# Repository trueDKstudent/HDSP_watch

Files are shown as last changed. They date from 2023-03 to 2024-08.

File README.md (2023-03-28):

## Wrist watch on HDSP-2000 indicators

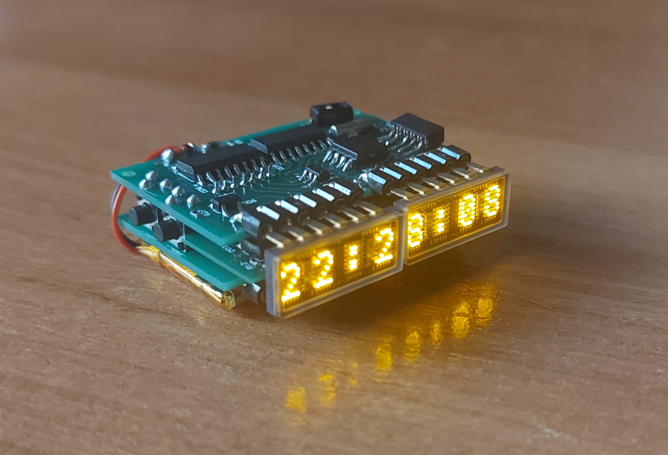
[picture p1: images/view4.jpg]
watch


### Introduction

Hello everyone, in this article I’d like to share with you my experience
in designing a digital wrist watch on rare and vintage LED indicators.
The main source of inspiration for this project came, of course, from
very unusual matrix LED indicators HDSP-2000 (fig. 1).

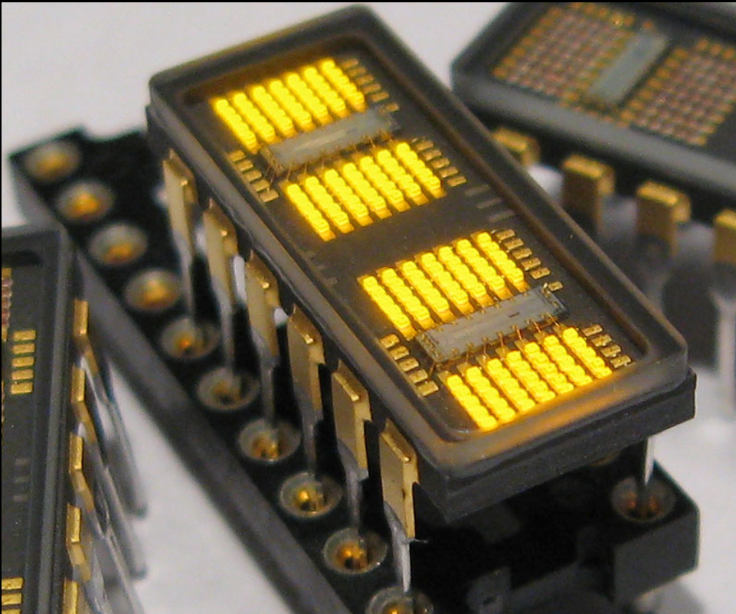
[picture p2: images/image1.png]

**Figure 1.**

When I saw them for the very first time I immediately fell in love with
them. First of all, it was very unlikely for me to ever find a 4 digit
matrix display in a 12-pin DIP ceramic package. Another stunning detail
about this display is that crystals on which located shift registers,
which are used to drive LED matrices, can be clearly seen through the
glass screen, as well as the golden wires that connect all the parts
together (fig. 2).

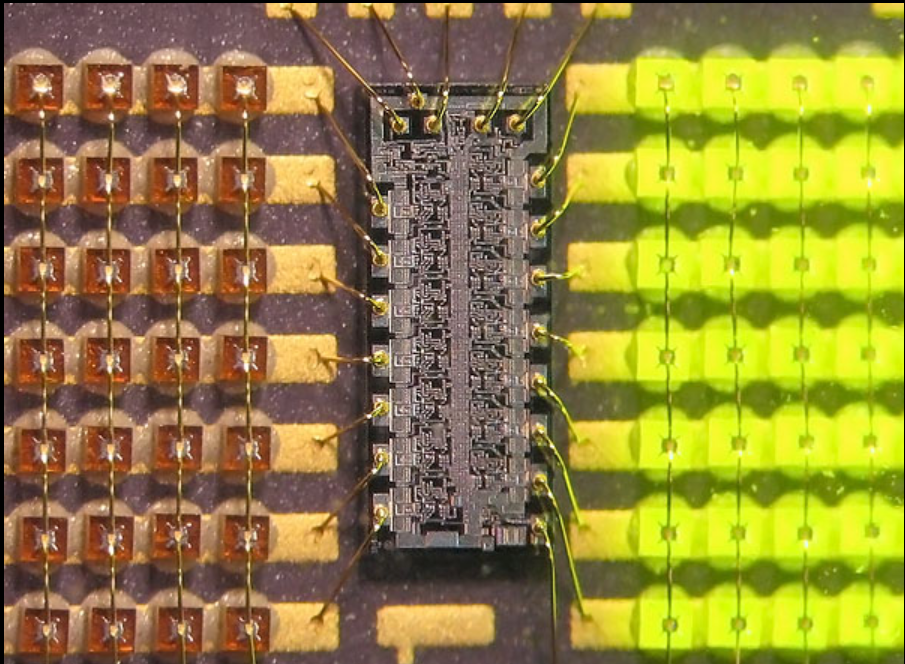
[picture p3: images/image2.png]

**Figure 2.**

I’ve bought several models of this displays, each of them has its own
color of light that is emitted from the LEDs.

- HDSP-2000 – has red LEDs and red filtering glass;
- HDPS-2001 – has yellow LEDs and clear glass;
- QDSP-2009 (HDSP-2002) – has green LEDs and clear glass as well;

As I got them I thought that it would be great idea to make on these
displays some sort of string line. The best devise into which I could
implement such a string, in my opinion, was a wrist watch. I think it
pretty cool to have a wrist watch with such an unusual and rare
indicators. Another reason why I decided to make this project is a lack
of any interesting tasks and projects, so I believed that designing of
this watches might be beneficial to my further grows as an electronic
engineer.

### Watches features

The first thing I decided to do was an inclusion of features, that will
have my wrist watch.

- The most obvious one is the display of time – hours, minutes and
seconds by clicking on specific button. A display of date, day of the
week, month, year and charge will be added as well.
- Another feature is indication of charging process, for example when
battery is charging some led should emit light and when the battery is
full – this led should turn off.
- The last feature is setting of time and date.

Of course, this is not the biggest list of possible features (alarm,
timers) but this watches do not need a myriad of them to be magnificent.
Just the look of its vintage indicators will make everyone adore it :)

Below are shown photos of finished wrist watch (without and with case).

With this link you can find video of this watch in action:
[link to video](https://drive.google.com/file/d/1nZPp8CitIWt24qjRfGPNrksItnVO5e3u/view?usp=share_link)

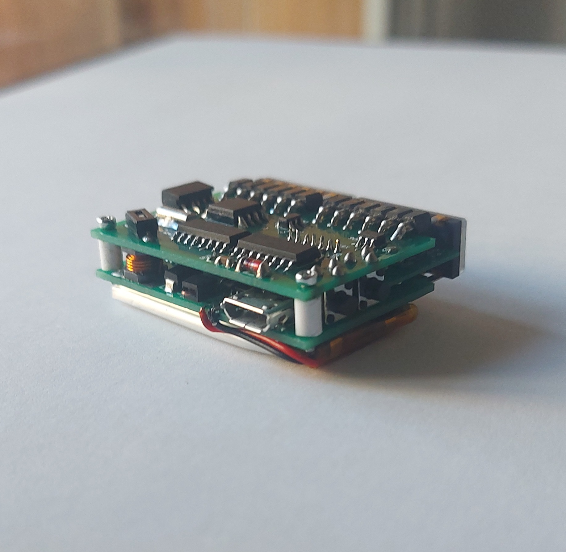
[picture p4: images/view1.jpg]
view 1


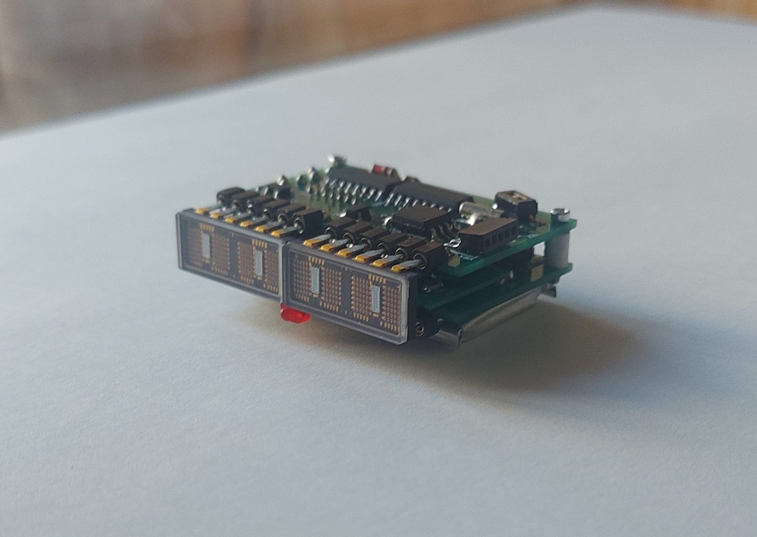
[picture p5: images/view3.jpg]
view 3


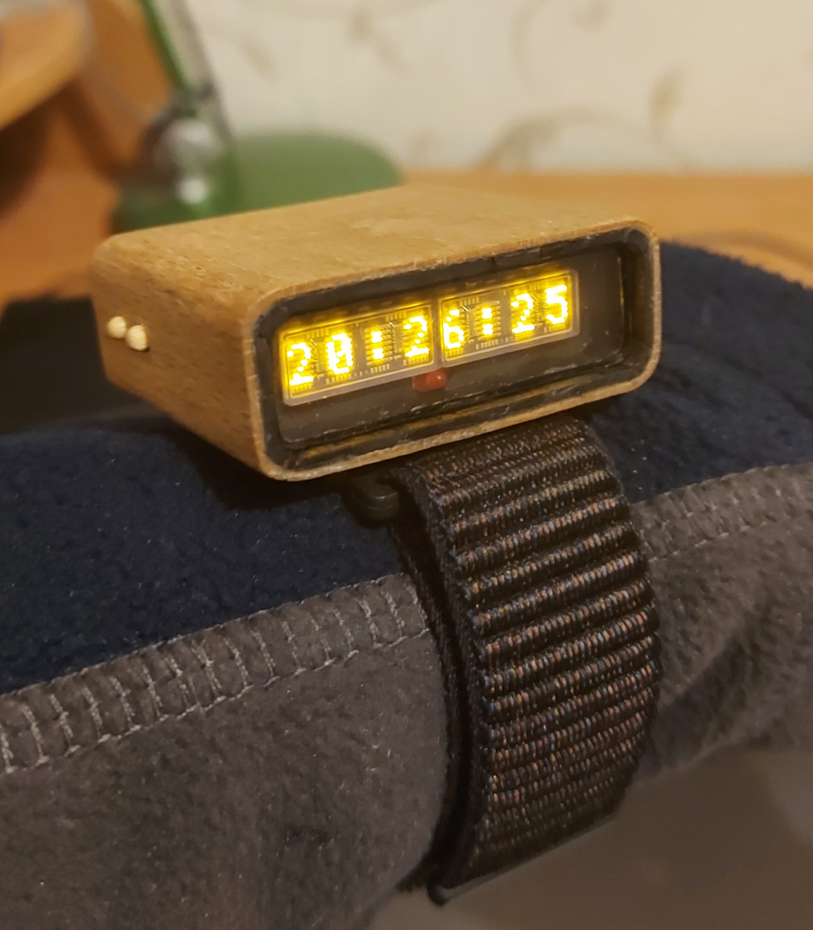
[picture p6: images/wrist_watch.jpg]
wrist watch


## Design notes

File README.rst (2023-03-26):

**Introduction**

Hello everyone, in this article I’d like to share with you my experience
in designing a digital wrist watch on rare and vintage LED indicators.
The main source of inspiration for this project came, of course, from
very unusual matrix LED indicators HDSP-2000 (fig. 1).


   Fig. 1

When I saw them for the very first time I immediately fell in love with
them. First of all, it was very unlikely for me to ever find a 4 digit
matrix display in a 12-pin DIP ceramic package. Another stunning detail
about this display is that crystals on which located shift registers,
which are used to drive LED matrices, can be clearly seen through the
glass screen, as well as the golden wires that connect all the parts
together (fig. 2).


   Fig. 2

I’ve bought several models of this displays, each of them has its own
color of light that is emitted from the LEDs.

- HDSP-2000 – has red LEDs and red filtering glass;

- HDPS-2001 – has yellow LEDs and clear glass;

- QDSP-2009 (HDSP-2002) – has green LEDs and clear glass as well;

As I got them I thought that it would be great idea to make on these
displays some sort of string line. The best devise into which I could
implement such a string, in my opinion, was a wrist watch. I think it
pretty cool to have a wrist watch with such an unusual and rare
indicators. Another reason why I decided to make this project is a lack
of any interesting tasks and projects, so I believed that designing of
this watches might be beneficial to my further grows as an electronic
engineer.

**Watches features**

The first thing I decided to do was an inclusion of features, that will
have my wrist watch.

- The most obvious one is the display of time – hours, minutes and
seconds by clicking on specific button. A display of date, day of the
week, month, year and charge will be added as well.

- Another feature is indication of charging process, for example when
battery is charging some led should emit light and when the battery is
full – this led should turn off.

- The last feature is setting of time and date.

Of course, this is not the biggest list of possible features (alarm,
timers) but this watches do not need a myriad of them to be magnificent.
Just the look of its vintage indicators will make everyone adore it :)

**Choosing the microcontoller**

When I was planing the entire project I also decided to make it more
challenging and interesting to me. And because of that chose a bit
unusual MCU for this watches. My pick stick to ATtiny85 - I beleived
that it would be an interesting challenge to make watch on this MC, but
later I had to switch to ATtiny85 and I will describe why so. Most basic
MC for such project would be ATmega328, which is used in Arduino UNO,
but again, it was not interesting enough to me and the solution on this
MC is already exist on the net.

Another reason why I’ve chosen AVR MCU but not ARM (STM32) or other is
because I’ve already had enough knowledge and skills about programming
such MCUs.

So, as you probably know, ATtiny85 has not a lot of pins, actually there
are only 5 pins which I could use to run an entire watch! It means that
I had to design various drivers and multiplexers to drive all the
devices with which ATtiny communicates.

**Display driver**

The key devices which are driven by MCU are of course indicators
HDSP-2000, without them entire project has no any sense. Due to the lack
of available pins in MCU, display driver should receive data from a
small amount of pins. If we look closer at the indicator, we’ll see that
it is basically a shift register which receives data through SPI bus. It
can be inferred, that the most vital signals for indicator are serial
clock and serial data signals. All other signals can be generated from
clock and data signals and I will explain how.

First of all, let’s have a look at columns signals. Each time a high
voltage level is applied to one of these pins the corresponding columns
in LED matrix are driven and the LEDs in this column emit light. It
means that after the new values have been stored to the shift registers
the next column should be driven. Basically, it is very similar to the
“running leds” projects, which can be easily built on decimal counters
like CD4017. Each time a new data is stored to the shift registers of
indicators, the counter CD4017 will count to the next value and the
corresponding output pin will drive the column of indicator.

Another problem is to get know when the transition of data to shift
registers is finished. This issue also can be solved with counters. By
counting the number of bits, which were transferred, it can be checked
whether or not the process is finished. In HDSP-2000 there are four
shift registers and each of them stores 7 bits, so the total data
capacity of indicator is 28 bits. Since two indicators are used in this
project, the capacity of display block is twice bigger, which is 56
bits. The amount of bits which were sent to the display can be obtained
from serial clock signal – each positive front of clock represents a one
bit of data that has been stored to the indicator. To count bits a
binary 7-stage counter CD4024 was used. The binary representation of
decimal number 56 is 111000, so the corresponding pins Q3, Q4, and Q5
are high when counter reach value 56. Early mentioned pins are tied to
single AND gate with 3 inputs. Output signal of AND gate is used as
clock signal for decimal counter CD4017. Since indicator HDSP-2000 has
only 5 columns counter CD4017 counts only from value 1 to 5. When
counter reaches value 5, corresponding pin “5” changes its state from
low to high and through RC low-pass filter sets high level on signal RST
while simultaneously driving fifth column of indicator. When high level
is set on RST pin of counter it resets its value. RC low-pass filter is
needed to create a time delay, so the fifth column could be driven for
some consistent time. The same solution was used to the output of AND
gate in order make sure that positive clock front for decimal counter
CD4017 would not disappear instantly after binary counter CD4024 resets.
The signal from AND gate is also used to bias current mirrors in
indicators which basically enables LEDs in indicator to emit light. By
changing resistance and capacitance in the RC filter it is possible to
regulate the width of pulses that AND gate produces. Consequently it
will make LEDs in indicator to “glow” for longer or lesser amount of
time which mean that it is possible to regulate a brightness of the
display. Timing diagram for the signals described above is shown on fig.
3.

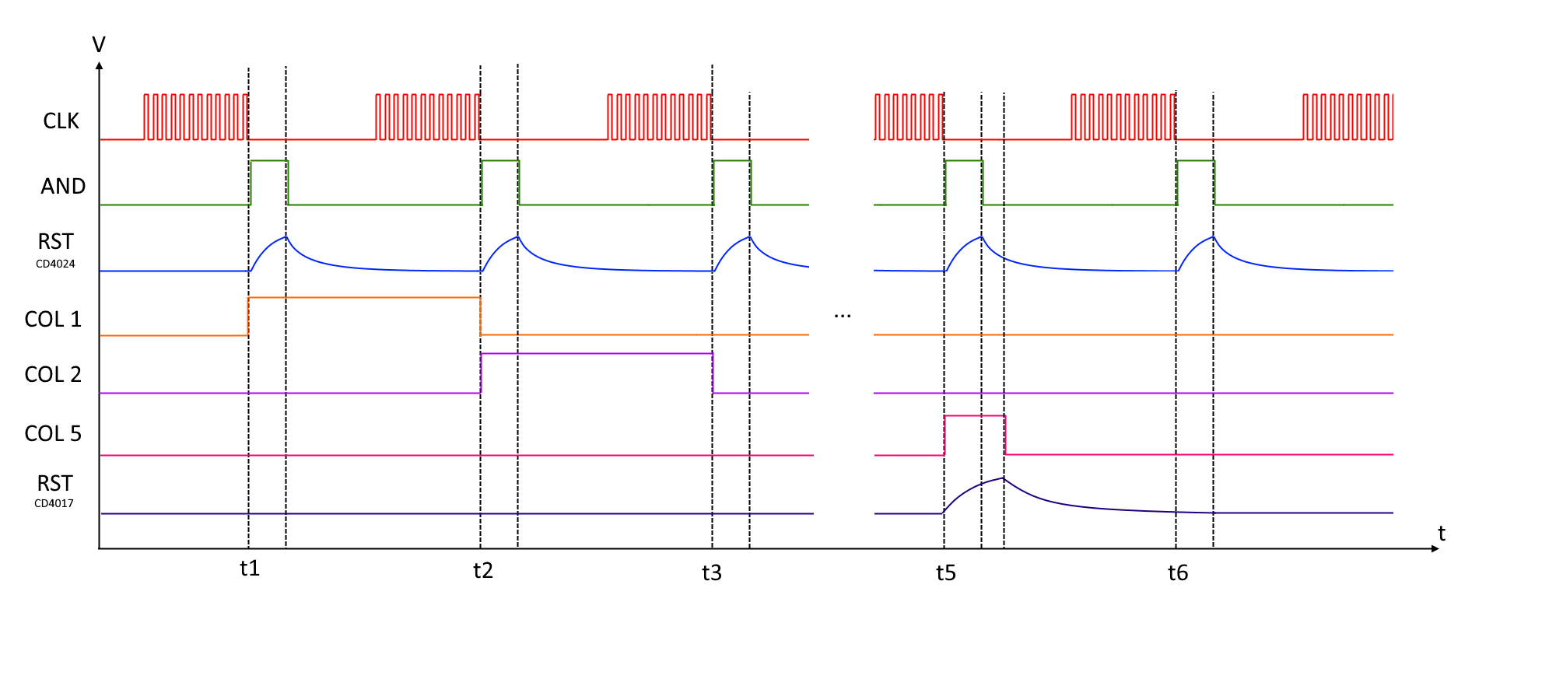
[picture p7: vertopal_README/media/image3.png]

   Fig. 3

Bipolar PNP transistors were used in order to provide a current for the
each column of the indicator. Since the low level signal is required to
open bipolar transistor and decimal counter can provide only high level
signal for each output pin it was decoded to use inverter on N-channel
MOS transistors.

**Supply core**

Supply core circuit consists of the next blocks:

- Accumulator;

- Charging circuit;

- DC-DC step up converter;

- Linear voltage regulator;

- Resistive divider of accumulator voltage;

Li-Po accumulator was chosen as a voltage source because of the next
advantages: it is rechargeable, it could be found in various sizes
rather than Li-Ion cells. The output voltage of li-po accumulator is in
range from 2.7 to 4.2 while all electronic components consume voltage of
3.3 V. To provide 3.3 V for all components a linear regulator XC6206 was
used. This regulator delivers 3.3 V on its out when voltage on its input
is higher than 3.4 V.

To monitor whether or not voltage on accumulator dropped to 3.4 V a
resistive divider was used. Voltage between two resistors is applied to
one of the pins of MC where it is then converted to binary code by ADC.
When display shows that battery charge is 0% it means that voltage on
accumulator is about 3.4 V, so the watch should be charged. Diode VD3
and capacitor C8 form a pic detector. Such a detector is needed due to
voltage drop of accumulator when indicators are turned on.

The main part of charging circuit is LTC4054 – a programmable linear
charger. Circuit itself is pretty simple: resistor R19 sets the charging
current which in this case is about 200 mA; LED HL1 indicates whether or
not battery has charged – when LED is on it means that the battery is
not full, when LED is off – battery is fully charged. Supply voltage for
this IC is 5 V which is delivered from USB. More information about how
does this circuit works can be found in datasheet for this IC.

DC-DC step-up converter is used in this watch to power HDSP indicators
since they require 5 V for proper operation while maximum voltage level
on battery can reach only 4.2 V. Circuit of this step-up converter was
taken from the datasheet for the IC that is used in this converter which
is SX1308. There will not be any explanation of how does this step-up
converter work since this is not the main aim but it is worth mention
the purpose of transistor VT11. This transistor is needed to disconnect
battery from converter when indicators are not used in order to reduce
power consumption of the watch when they are turned off.

**Control core**

Control core consists of the following blocks:

- MC ATtiny 85;

- Multiplexers;

- Real time clock;

- HDSP indicators;

- Voltage shifters;

- Buttons;

The main processing unit of the entire watch is microcontroller ATtiny
85. In total only two pins are required to run indicators, four to
program MC and other two to communicate with RTC. Those pins are PB2
(SCK / SCL), PB1 (MISO), PB0 (MOSI / SDA) and PB5 (RESET). HDSP-2000
indicators use SPI bus to transfer data so pins PB1 and PB2 are used to
send data to the indicators. RTC DS1337 use I2C bus to exchange data
with MC and because of that it was decided to use pins PB2 and PB0 to
communicate with MC. The last one group of pins is used to program MC
through UART interface. To do so signal pins PB0, PB1, PB2 and PB5
should be connected to the programming device. Since all the devices
that are connected to those pins cannot be connected together with each
other simultaneously due to data collisions it is better to multiplex
all the signals in different moments of time.

**Signals multiplexing**

First of all it is better to establish function of switching between
programming mode and operating mode. This task is solved by usage of
analog multiplexer DD8 (CD4053) which has three 1 to 2 multiplexers. It
was decided to use analog multiplexers because data is being transferred
in both direction. When LOW level is present on pins A, B and C of
multiplexer pins ax, bx and cx are tied to az, bz and cz respectively.
In this case watch operates in showing time mode and pins PB0, PB1 and
PB2 are connected to periphery (indicators, RTC, buttons). When HIGH
level is applied to multiplexer’s control pins outputs ay, by and cy are
tied to input pins az, bz and cz which means that watch is operating in
programming mode and pins PB0, PB1 and PB2 are connected to programming
port XS7. Switching between modes is done by external switch SW3.

Pin ax of DD8 is used to transfer clock signal CLK_BUS from MC to HDSP
indicators and RTC. Because indicators and RTC use different buses it is
better to multiplex clock signal so the clock inputs of both indicators
and RTC will be isolated from each other. To do so multiplexer DD9
(CD4053) is used. Pin bx of DD8 is used to transfer serial data to
indicators. Since indicators operate on 5V shifters DD5 and DD6 are used
to convert 3.3V D_OUT and SCLK signals to 5V signals. Pin cx of DD8 is
used to exchange data between MC and RTC via I2C bus. Pins bx and by are
used to measure buttons state and battery voltage level and pins ax and
ay are used to drive MOS transistor VT11 in supply core.

**Buttons control and battery voltage measurement**

Since MC Attiny 85 has limited amount of pins that can be used as inputs
for buttons signals, it is way more convenient to represent signals from
multiple buttons as different voltage levels. It can be accomplished by
voltage dividers. In supply core there are two buttons: SW1 and SW2. If
voltage level on net *Buttons* is equal to 0V it means that SW1 is
pressed, if level is higher than 0V – SW2 is pressed. Note that such
configuration of voltage divider and buttons does not support multiple
press on both button because in this case voltage level on the net still
will be 0V. Later voltage level on the net is measured by builtin ADC in
microcontroller and converted to digital code. By comparing the ADC
output code it can be figured out which button is pressed.

Voltage level of battery is measured via voltage divider R20-R23 in
supply core, since its voltage can reach values of 4.2V while maximum
operating voltage of MC is 3.3V. Voltage divider provides only half of
battery voltage, so it is safer for ADC to measure it. Also voltage from
battery is applied to resistive divider R20-R23 through peak detector
VD3-C8. Peak detector is needed because battery voltage drops when load
is applied to it, like DC-DC step-up converter for indicators.

Finally, diode VD2 and integrator C7-R32 are used to keep DC-DC boost
converter active while data is being sent to indicators. Without this
solution text on display would blink.

Oops, seems like this is the end of the article :(

later I will add my PCB design adventures here, so stay tuned for
updates





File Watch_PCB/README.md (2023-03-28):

### Choosing the microcontoller

When I was planing the entire project I also decided to make it more
challenging and interesting to me. And because of that chose a bit
unusual MCU for this watches. My pick stick to ATtiny85 - I beleived
that it would be an interesting challenge to make watch on this MC, but
later I had to switch to ATtiny85 and I will describe why so. Most basic
MC for such project would be ATmega328, which is used in Arduino UNO,
but again, it was not interesting enough to me and the solution on this
MC is already exist on the net.

Another reason why I’ve chosen AVR MCU but not ARM (STM32) or other is
because I’ve already had enough knowledge and skills about programming
such MCUs.

So, as you probably know, ATtiny85 has not a lot of pins, actually there
are only 5 pins which I could use to run an entire watch! It means that
I had to design various drivers and multiplexers to drive all the
devices with which ATtiny communicates.

### Display driver

The key devices which are driven by MCU are of course indicators
HDSP-2000, without them entire project has no any sense. Due to the lack
of available pins in MCU, display driver should receive data from a
small amount of pins. If we look closer at the indicator, we’ll see that
it is basically a shift register which receives data through SPI bus. It
can be inferred, that the most vital signals for indicator are serial
clock and serial data signals. All other signals can be generated from
clock and data signals and I will explain how.

First of all, let’s have a look at columns signals. Each time a high
voltage level is applied to one of these pins the corresponding columns
in LED matrix are driven and the LEDs in this column emit light. It
means that after the new values have been stored to the shift registers
the next column should be driven. Basically, it is very similar to the
“running leds” projects, which can be easily built on decimal counters
like CD4017. Each time a new data is stored to the shift registers of
indicators, the counter CD4017 will count to the next value and the
corresponding output pin will drive the column of indicator. Schematic
of indicator is shown on fig. 1.

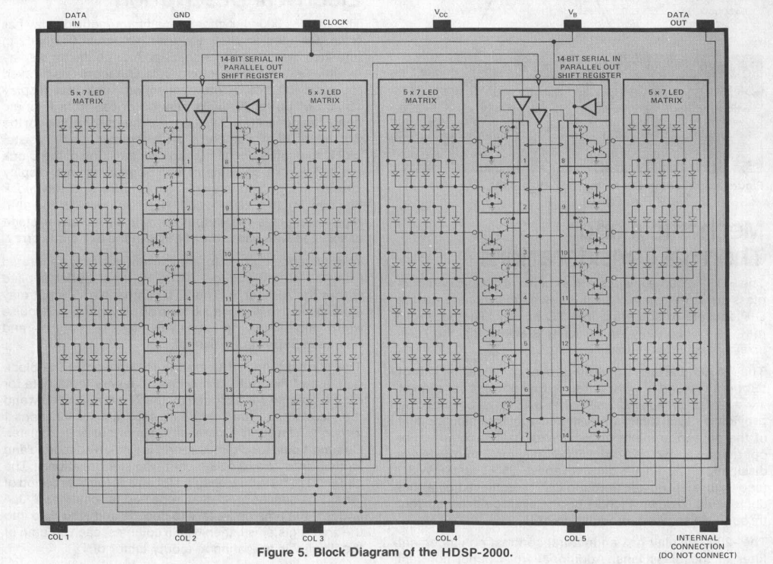
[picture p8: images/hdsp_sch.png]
indicator schematic

**Figure 1.** - HDSP-2000 indicator schematic

Another problem is to get know when the transition of data to shift
registers is finished. This issue also can be solved with counters. By
counting the number of bits, which were transferred, it can be checked
whether or not the process is finished. In HDSP-2000 there are four
shift registers and each of them stores 7 bits, so the total data
capacity of indicator is 28 bits. Since two indicators are used in this
project, the capacity of display block is twice bigger, which is 56
bits. The amount of bits which were sent to the display can be obtained
from serial clock signal – each positive front of clock represents a one
bit of data that has been stored to the indicator. To count bits a
binary 7-stage counter CD4024 was used. The binary representation of
decimal number 56 is 111000, so the corresponding pins Q3, Q4, and Q5
are high when counter reach value 56. Early mentioned pins are tied to
single AND gate with 3 inputs. Output signal of AND gate is used as
clock signal for decimal counter CD4017. Drivers schematic is shown on
fig. 2.

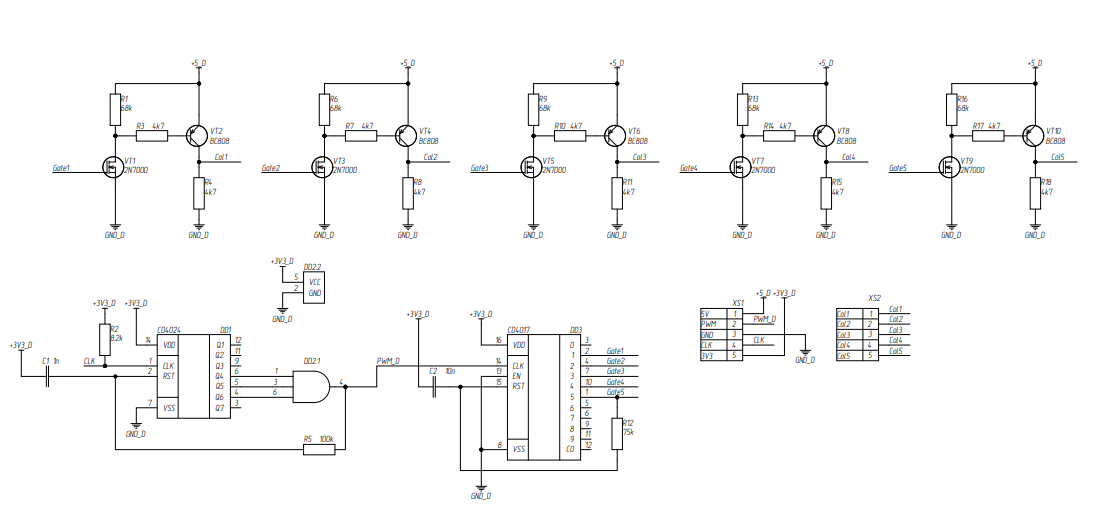
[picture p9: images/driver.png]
driver

**Figure 2.** - Display driver schematic

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


**Figure 3.** - Timing diagram of signals in display driver

Bipolar PNP transistors were used in order to provide a current for the
each column of the indicator. Since the low level signal is required to
open bipolar transistor and decimal counter can provide only high level
signal for each output pin it was decoded to use inverter on N-channel
MOS transistors.

### Supply core

Supply core circuit (fig. 4) consists of the next blocks:

- Accumulator;
- Charging circuit;
- DC-DC step up converter;
- Linear voltage regulator;
- Resistive divider of accumulator voltage;

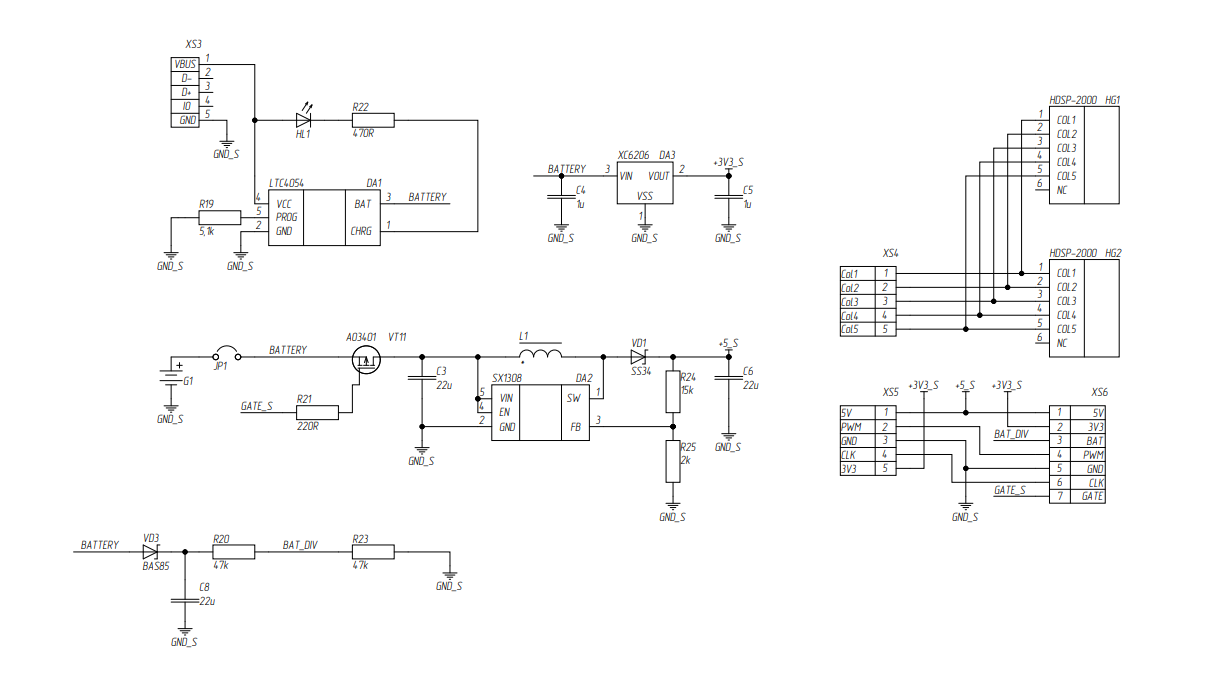
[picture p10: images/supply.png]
supply

**Figure 4.** - Supply core schematic

Li-Po accumulator was chosen as a voltage source because of the next
advantages: it is rechargeable, it could be found in various sizes
rather than Li-Ion cells. The output voltage of li-po accumulator is in
range from 2.7 to 4.2 while all electronic components consume voltage of
3.3 V. To provide 3.3 V for all components a linear regulator XC6206 was
used. This regulator delivers 3.3 V on its out when voltage on its input
is higher than 3.4 V.

To monitor whether or not voltage on accumulator dropped to 3.4 V a
resistive divider was used. Voltage between two resistors is applied to
one of the pins of MC where it is then converted to binary code by ADC.
When display shows that battery charge is 0% it means that voltage on
accumulator is about 3.4 V, so the watch should be charged. Diode VD3
and capacitor C8 form a pic detector. Such a detector is needed due to
voltage drop of accumulator when indicators are turned on.

The main part of charging circuit is LTC4054 – a programmable linear
charger. Circuit itself is pretty simple: resistor R19 sets the charging
current which in this case is about 200 mA; LED HL1 indicates whether or
not battery has charged – when LED is on it means that the battery is
not full, when LED is off – battery is fully charged. Supply voltage for
this IC is 5 V which is delivered from USB. More information about how
does this circuit works can be found in datasheet for this IC.

DC-DC step-up converter is used in this watch to power HDSP indicators
since they require 5 V for proper operation while maximum voltage level
on battery can reach only 4.2 V. Circuit of this step-up converter was
taken from the datasheet for the IC that is used in this converter which
is SX1308. There will not be any explanation of how does this step-up
converter work since this is not the main aim but it is worth mention
the purpose of transistor VT11. This transistor is needed to disconnect
battery from converter when indicators are not used in order to reduce
power consumption of the watch when they are turned off.

### Control core

Control core (fig. 5) consists of the following blocks:

- MC ATtiny 85;
- Multiplexers;
- Real time clock;
- HDSP indicators;
- Voltage shifters;
- Buttons;

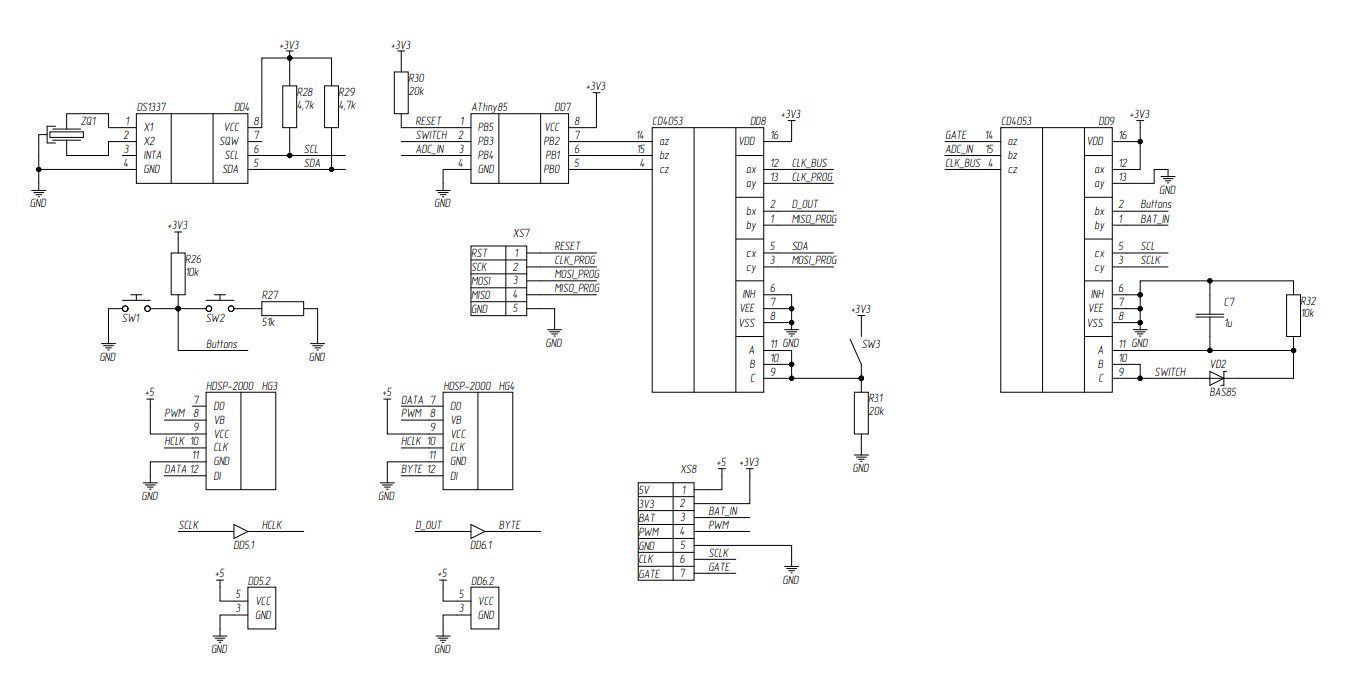
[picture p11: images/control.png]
control

**Figure 5.** - Control core schematic

The main processing unit of the entire watch is microcontroller ATtiny
85. In total only two pins are required to run indicators, four to
program MC and other two to communicate with RTC. Those pins are PB2
(SCK / SCL), PB1 (MISO), PB0 (MOSI / SDA) and PB5 (RESET). HDSP-2000
indicators use SPI bus to transfer data so pins PB1 and PB2 are used to
send data to the indicators. RTC DS1337 use I2C bus to exchange data
with MC and because of that it was decided to use pins PB2 and PB0 to
communicate with MC. The last one group of pins is used to program MC
through UART interface. To do so signal pins PB0, PB1, PB2 and PB5
should be connected to the programming device. Since all the devices
that are connected to those pins cannot be connected together with each
other simultaneously due to data collisions it is better to multiplex
all the signals in different moments of time.

### Signals multiplexing

First of all it is better to establish function of switching between
programming mode and operating mode. This task is solved by usage of
analog multiplexer DD8 (CD4053) which has three 1 to 2 multiplexers. It
was decided to use analog multiplexers because data is being transferred
in both direction. When LOW level is present on pins A, B and C of
multiplexer pins ax, bx and cx are tied to az, bz and cz respectively.
In this case watch operates in showing time mode and pins PB0, PB1 and
PB2 are connected to periphery (indicators, RTC, buttons). When HIGH
level is applied to multiplexer’s control pins outputs ay, by and cy are
tied to input pins az, bz and cz which means that watch is operating in
programming mode and pins PB0, PB1 and PB2 are connected to programming
port XS7. Switching between modes is done by external switch SW3.

Pin ax of DD8 is used to transfer clock signal CLK_BUS from MC to HDSP
indicators and RTC. Because indicators and RTC use different buses it is
better to multiplex clock signal so the clock inputs of both indicators
and RTC will be isolated from each other. To do so multiplexer DD9
(CD4053) is used. Pin bx of DD8 is used to transfer serial data to
indicators. Since indicators operate on 5V shifters DD5 and DD6 are used
to convert 3.3V D_OUT and SCLK signals to 5V signals. Pin cx of DD8 is
used to exchange data between MC and RTC via I2C bus. Pins bx and by are
used to measure buttons state and battery voltage level and pins ax and
ay are used to drive MOS transistor VT11 in supply core.

### Buttons control and battery voltage measurement

Since MC Attiny 85 has limited amount of pins that can be used as inputs
for buttons signals, it is way more convenient to represent signals from
multiple buttons as different voltage levels. It can be accomplished by
voltage dividers. In supply core there are two buttons: SW1 and SW2. If
voltage level on net *Buttons* is equal to 0V it means that SW1 is
pressed, if level is higher than 0V – SW2 is pressed. Note that such
configuration of voltage divider and buttons does not support multiple
press on both button because in this case voltage level on the net still
will be 0V. Later voltage level on the net is measured by builtin ADC in
microcontroller and converted to digital code. By comparing the ADC
output code it can be figured out which button is pressed.

Voltage level of battery is measured via voltage divider R20-R23 in
supply core, since its voltage can reach values of 4.2V while maximum
operating voltage of MC is 3.3V. Voltage divider provides only half of
battery voltage, so it is safer for ADC to measure it. Also voltage from
battery is applied to resistive divider R20-R23 through peak detector
VD3-C8. Peak detector is needed because battery voltage drops when load
is applied to it, like DC-DC step-up converter for indicators.

Finally, diode VD2 and integrator C7-R32 are used to keep DC-DC boost
converter active while data is being sent to indicators. Without this
solution text on display would blink.

### PCB Design

All PCBs and schematics were designed in **Altium designed V20**.
At first I tried to make PCBs by myself but after I got them I realized
that its quality is not satisfying. After that I assumed that it would 
be better to order my PCBs from a company that specializes in its 
manufacturing. My ordered PCBs that I got from this shop are shown below.

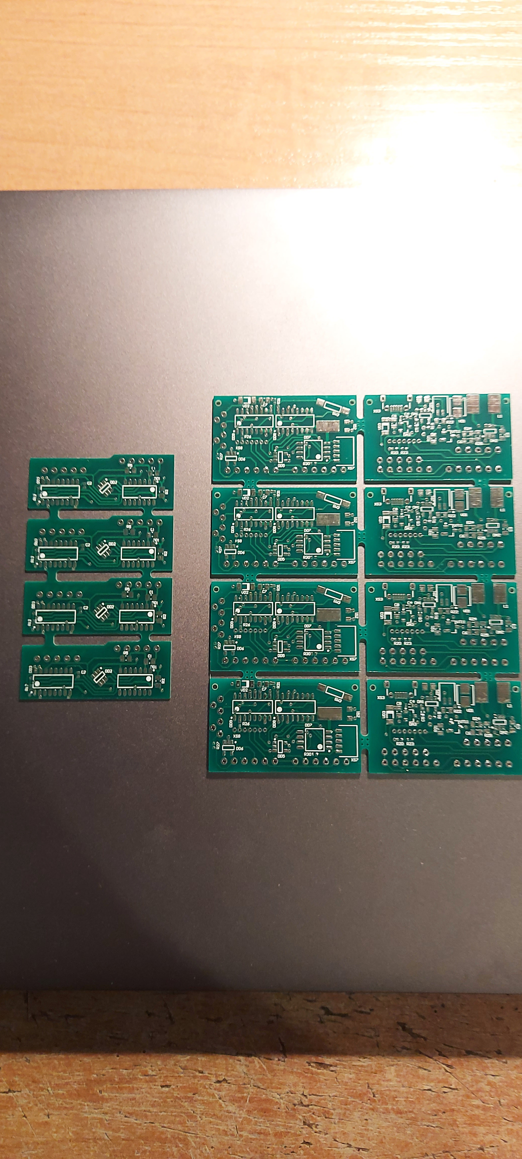
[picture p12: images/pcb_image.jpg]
pcb1


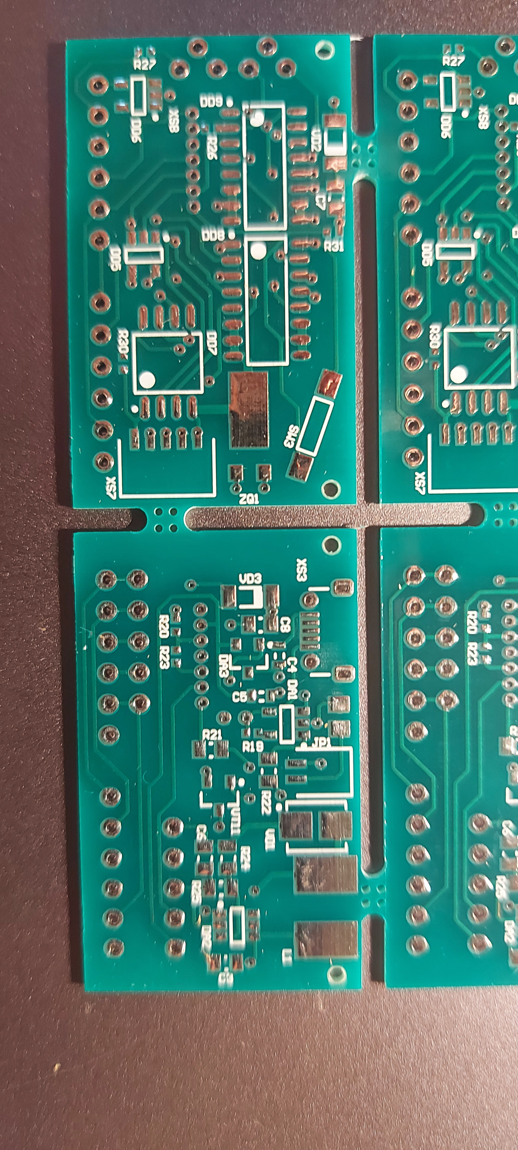
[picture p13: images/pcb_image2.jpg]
pcb2


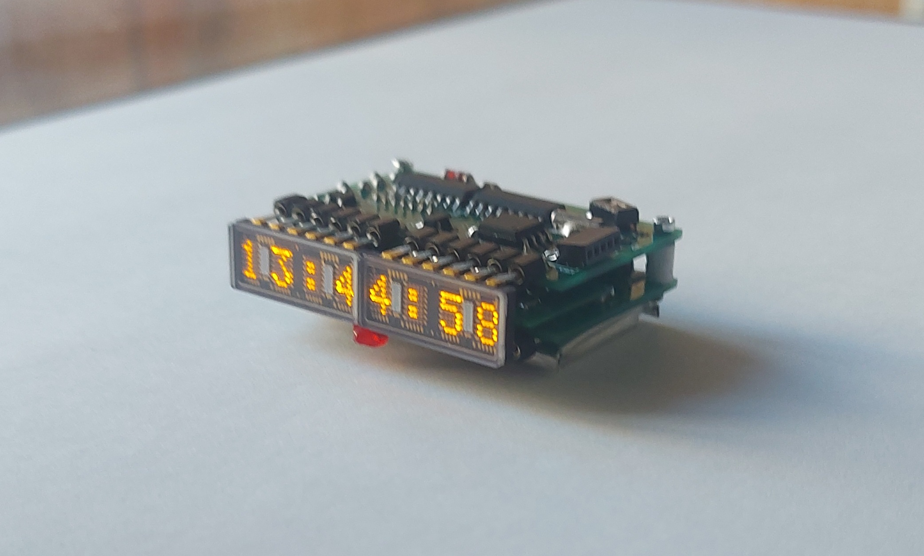
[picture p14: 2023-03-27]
images/view2.jpg

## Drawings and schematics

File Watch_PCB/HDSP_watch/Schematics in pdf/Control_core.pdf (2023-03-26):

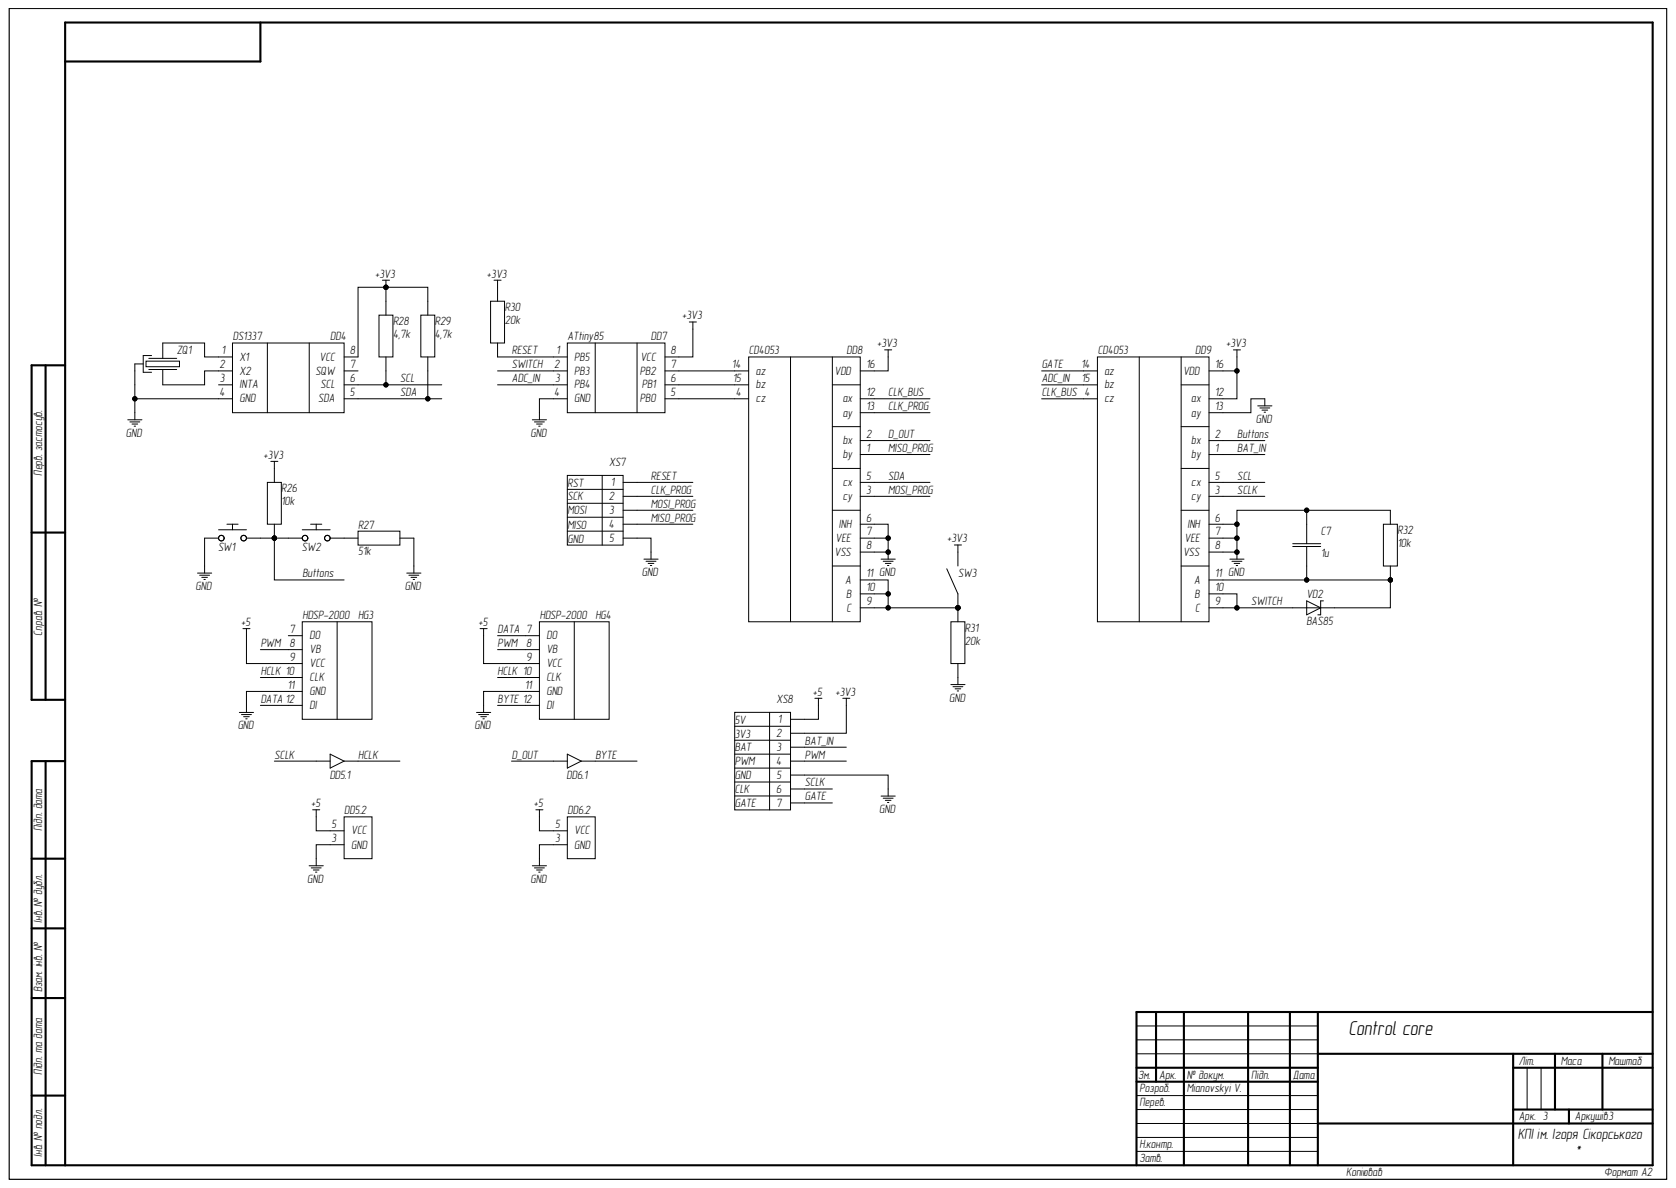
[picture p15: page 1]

Інв. № подл. Підп. та дата Взам. інв. № Інв. № дубл. Підп. дата Справ. № Перв. застосув.

RST
SCK MOSI MISO

GND

BAT | 1234567
5V
3V3

PWM
CL K
GATE

SCLK

Co ntrol core

Л іт. | Маса | Маш таб

Зм. | Арк. | № докум. | Підп. | Дата
Розроб. | | Mianovskyi V.
Перев. Н.контр | Арк. 3 | Аркуші в 3

Затв.

КПІ і м. Ігоря Сікорського *

ALTIUM GOSTBOM | 2.0 KE V

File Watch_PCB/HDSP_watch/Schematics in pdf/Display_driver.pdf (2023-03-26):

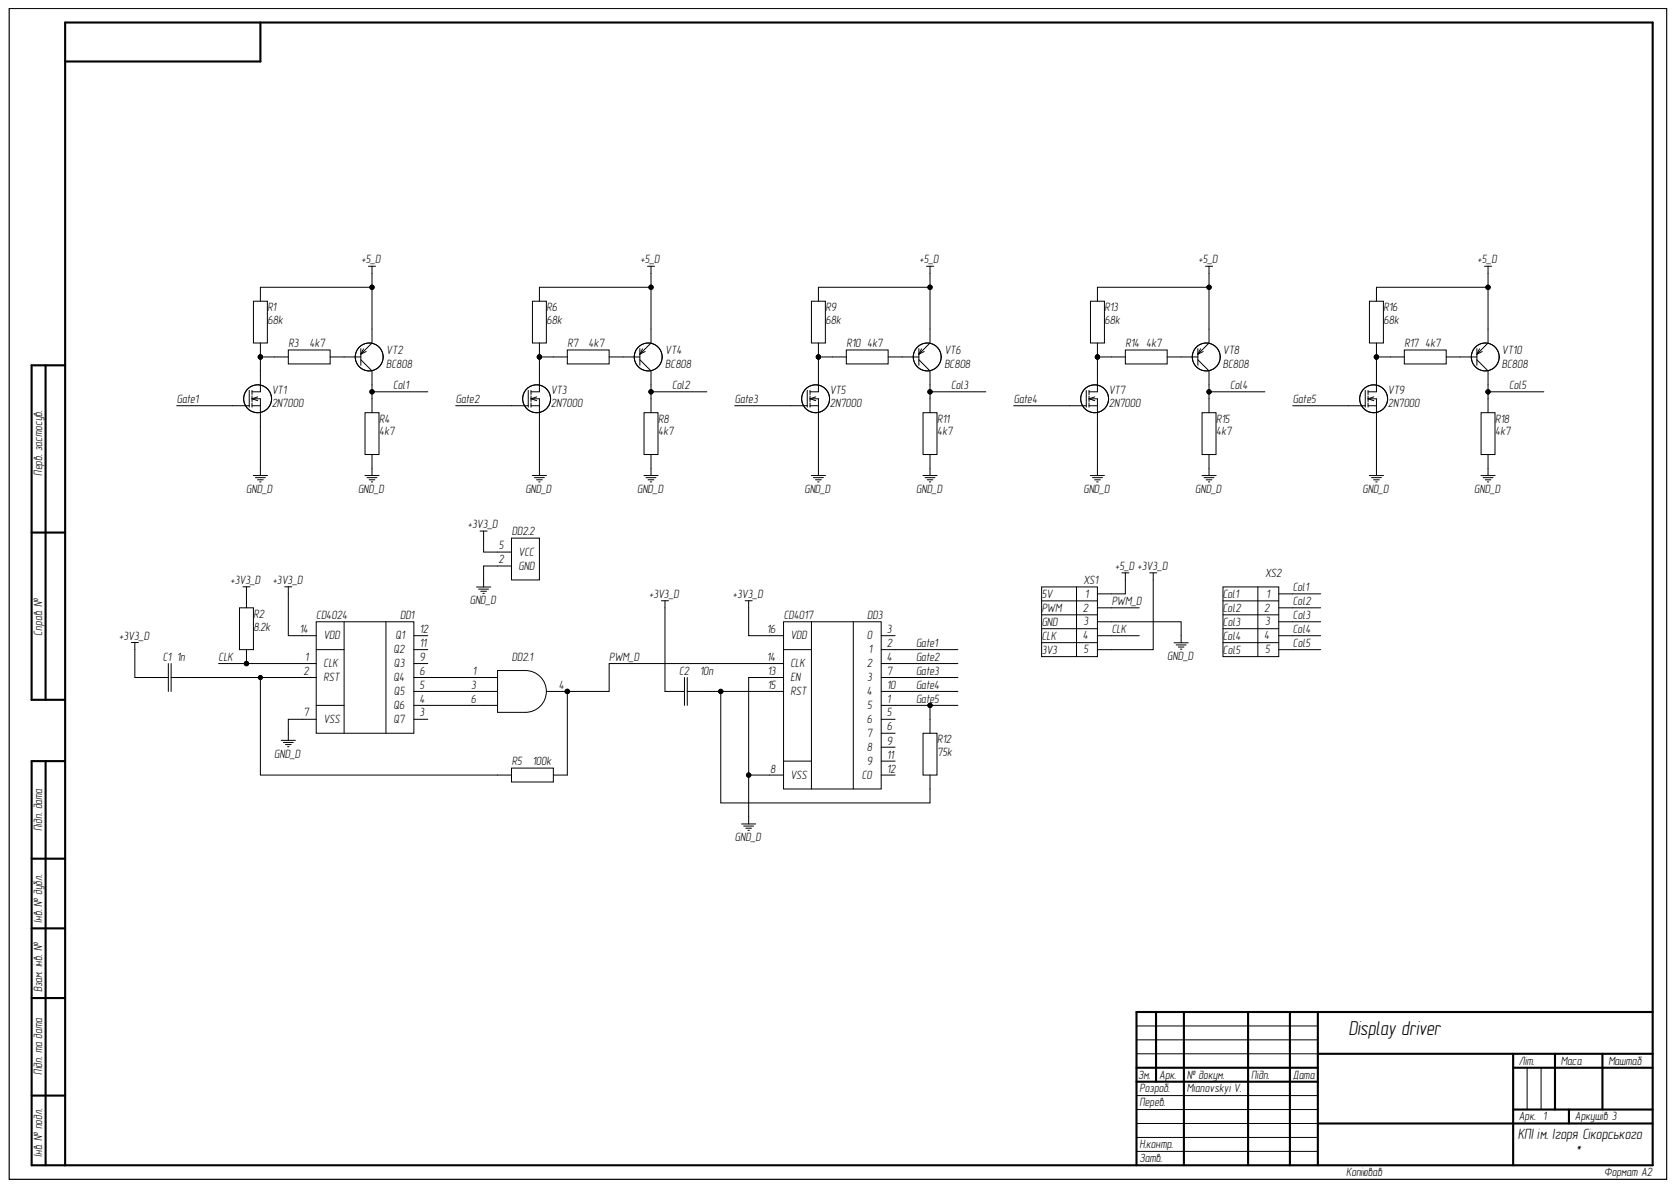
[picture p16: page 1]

Інв. № подл. Підп. та дата Взам. інв. № Інв. № дубл. Підп. дата Справ. № Перв. застосув.

Display driver

Літ. | Маса | Маштаб

Зм. | Арк. | № докум. | Підп. | Дата
Розроб. | | Mianovskyi V.
Перев.

Арк. 1 | Аркушів 3
КПІ ім. Ігоря Сікорського *

Н.контр.
Затв.

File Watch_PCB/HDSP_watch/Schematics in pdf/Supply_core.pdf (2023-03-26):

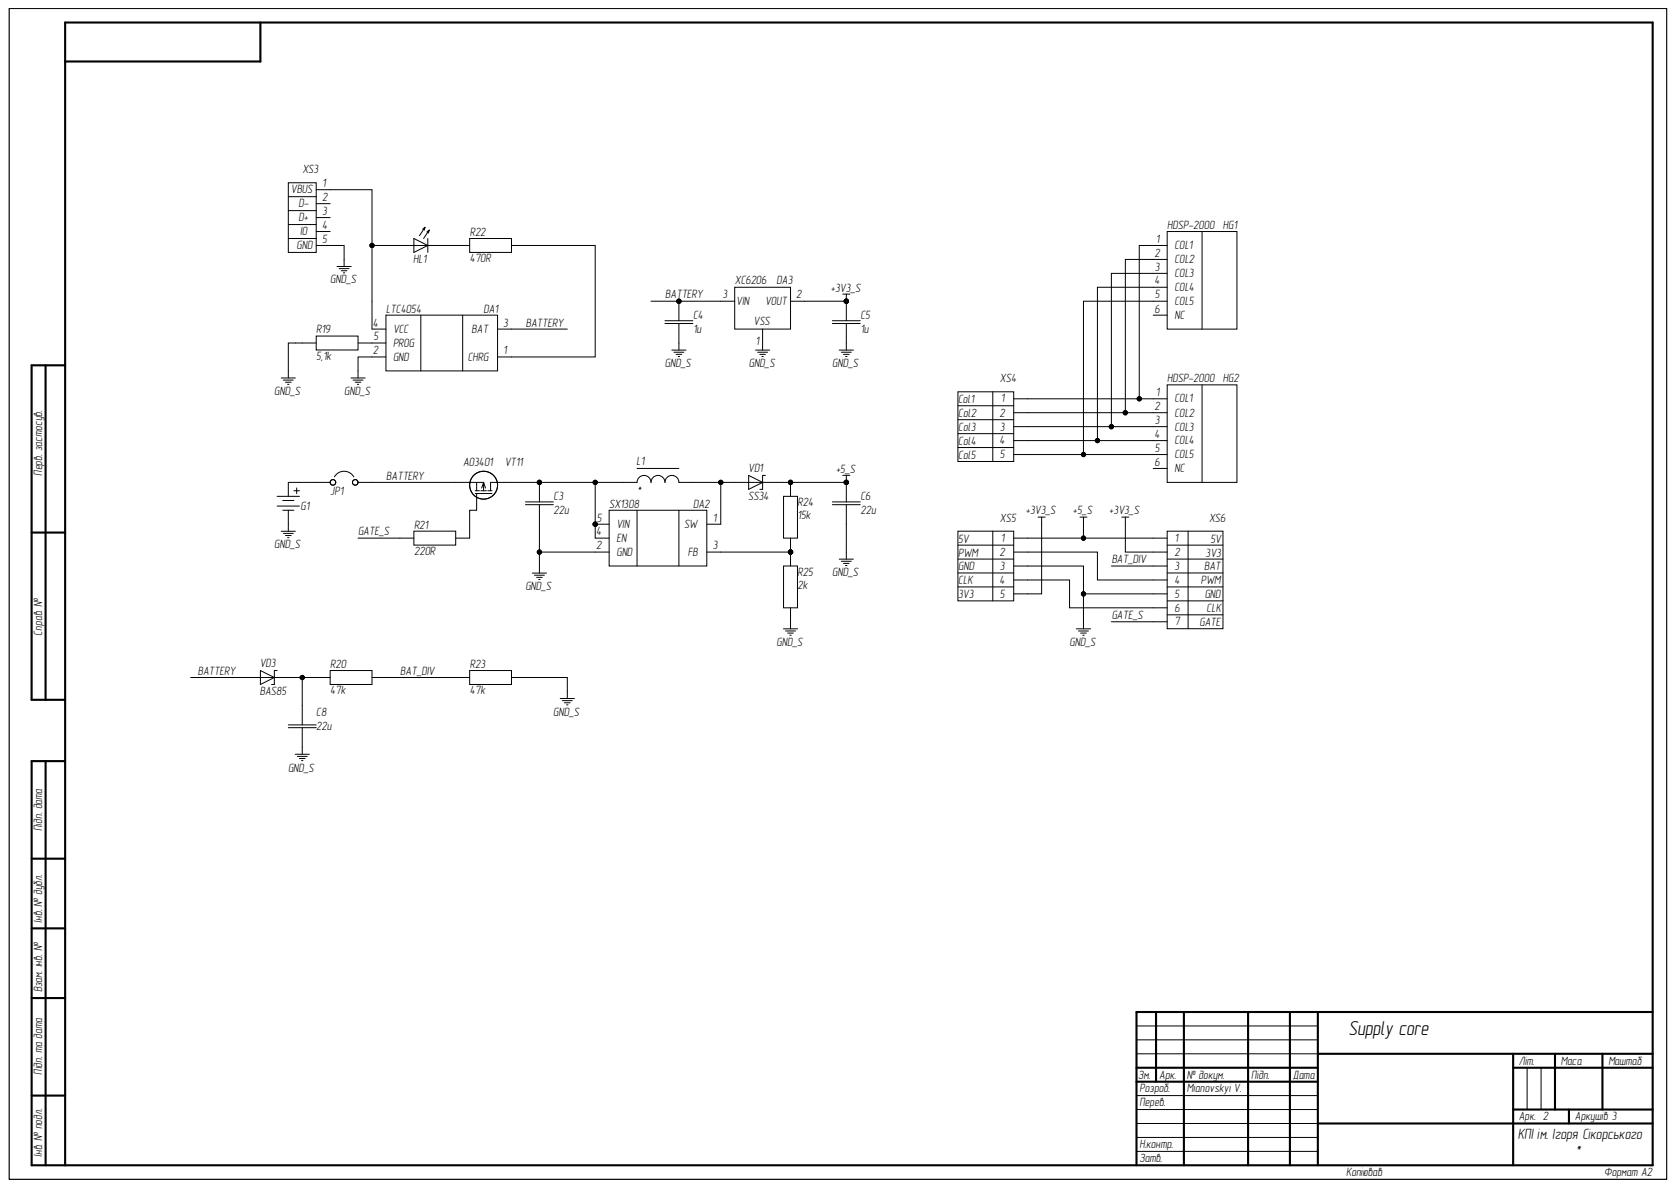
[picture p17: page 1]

VCC PROG GND | BAT CHRG

Col2 | 12345
Col1

Інв. № подл. Підп. та дата Взам. інв. № Інв. № дубл. Підп. дата Справ. № Перв. застосув.

Col3
Col4
Col5

VIN EN | SW
4 | FB

BAT_DIV

CL K | | PWM
3V3 | | GND

CL K
GATE

Supply c ore

Л іт. | Маса | Маш таб

Зм. | Арк. | № докум. | Підп. | Дата
Розроб. | | Mianovskyi V.
Перев. Н.контр | Арк. 2 | Аркуші в 3

Затв.

КПІ і м. Ігоря Сікорського *

ALTIUM GOSTBOM | 2.0 KE V

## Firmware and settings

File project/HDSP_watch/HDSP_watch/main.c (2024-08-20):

/*
 * HDSP_watch.c
 *
 * Created: 01.04.2022 19:29:26
 * Author : Dr. Space
 */ 

#include <avr/sleep.h>
#include <stdlib.h>
#include "DS1337.h"
#include "HDSP_2000.h"
#include "ADC.h"

char text[55];

void TaskShowTime(void)
{
    char tim[8];
    uint8_t ptr = 0;
    uint8_t n=0;
    
    memset(text, ' ', 55); // preparing string that will show time
    
    // in each iteration ptr varible increments by 1 with delay of 125 ms.
    // It means that each time text with time will shift by one digit to
    // the left. When ptr = 9 text will stop shifting for 124*24 ms. After
    // that text will continue to shift until it will disappear on display
    while(ptr < 16){
        DS1337GetTime(tim);
        strncpy(text+8, tim, 8);
        SPIInit();
        _delay_us(80);
        HDSPSendText(text+ptr, 125);
        ptr++;
        
        if(ptr == 9 && n<24) ptr=8, n++;
        else n=0;

        I2CInit();
    }
}

void TaskShowDateAndCharge(void)
{
    char tim[30];
    uint8_t ptr = 0, ptr2;
    uint8_t ln = 1, n = 0;
    uint8_t charge;
    int adc_input;
    
    memset(text, ' ', 55);
    memset(tim, 0, 30);

    // read the voltage value of battery
    PORTB |= (1<<PB3);
    adc_input = ADCConvert();
    adc_input = ((adc_input - 491) / 5) * 4;
    PORTB &= ~(1<<PB3);
    charge = adc_input;

    n = charge/100;
    
    adc_input = charge;
    
    // this loop sends date (day, month, year and charge) to display.
    // The text scrols to the left.
    do{
        charge = adc_input;
        DS1337GetDate(tim);
        ln = strlen(tim);
        ptr2 = 21+ln+(n);
        strncpy(text+8, tim, ln);
        strncpy(text+8+ln, ", Charge: ", 10);
        text[ptr2-1] = '%';
        text[ptr2-2] = 0x30 | (charge % 10);
        charge /= 10;
        text[ptr2-3] = 0x30 | (charge % 10);
        charge /= 10;
        text[ptr2-4] = (0x20 + (n<<4)) | charge;
        SPIInit();
        HDSPSendText(text+ptr, 200);
        ptr++;
        memset(tim, 0, 30);
        I2CInit();
    } while(ptr < ptr2);
}

void TaskSetTime(void)
{
    // max values for settings: max year, max date...
    // Remark: in RTC DS1337 monthes, dates and day of the week
    // start from value 0
    uint8_t hor=0, min=0, sec=0, day=0, mon=0, dat=0, yer=0;
    uint8_t max_val[7] = {99, 30, 11, 6, 59, 59, 23};
    uint8_t *ptr3;
    uint8_t n = 7; // the number of settings
    uint8_t button_state = BUT_SLEEP;                            

    while(n>0) {
    	
    	strcpy_P(text, (char *)pgm_read_word(&(set_table[n-1])));
    	SPIInit();
    	HDSPScroolTextDown2(text, 80); // scrool text down starting with empty screen

        do {
    	switch(n) {
    		case 7:
    		ptr3 = &hor;
    		text[6] = 0x30 | (DS1337GetBCD(hor) >> 4);
    		text[7] = 0x30 | (DS1337GetBCD(hor) & 0x0F);
    		break;
    		case 6:
    		ptr3 = &min;
    		text[6] = 0x30 | (DS1337GetBCD(min) >> 4);
    		text[7] = 0x30 | (DS1337GetBCD(min) & 0x0F);
    		break;
    		case 5:
    		ptr3 = &sec;
    		text[6] = 0x30 | (DS1337GetBCD(sec) >> 4);
    		text[7] = 0x30 | (DS1337GetBCD(sec) & 0x0F);
    		break;
    		case 4:
    		ptr3 = &day;
    		strcpy_P(text+5, (char *)pgm_read_word(&(days_table[day])));
    		break;
    		case 3:
    		ptr3 = &mon;
    		strcpy_P(text+5, (char *)pgm_read_word(&(monthes_table[mon])));
    		break;
    		case 2:
    		ptr3 = &dat;
    		text[6] = 0x30 | (DS1337GetBCD(dat+1) >> 4);
    		text[7] = 0x30 | (DS1337GetBCD(dat+1) & 0x0F);
    		break;
    		case 1:
    		ptr3 = &yer;
    		text[6] = 0x30 | (DS1337GetBCD(yer) >> 4);
    		text[7] = 0x30 | (DS1337GetBCD(yer) & 0x0F);
    		break;
    		default:
    		ptr3 = &hor;
    		break;
    	}
    	
    	SPIInit();
    	HDSPSendText(text, 150);
    	I2CInit();
    	
        // here goes incrementation of one of the values that are being modified
    	button_state = ADCGetButtonState();
        if(button_state == BUT_SW_CHRG) (*ptr3)++;
        (*ptr3) %= (max_val[n-1] + 1);
        
        }while(button_state != BUT_SET_TIME);
        
    	n--;
    	SPIInit();
    	HDSPScroolTextDown(text, 80); // scrool text down
    	I2CInit();   
    }
    // write new date to RTC
    DS1337SetTime(hor, min, sec, day, mon, dat, yer);
}

int main(void)
{
    uint8_t button_state;
    
	PortInit();
	PWMInit();
	ADCInit();
	I2CInit();
	DS1337Init();
	PcIntInit();
	set_sleep_mode(SLEEP_MODE_PWR_DOWN);
	
	while (1)
    {	
		sleep_mode();
		PcIntDeinit();

		TaskShowTime();
		button_state = ADCGetButtonState();
        
        if(button_state == BUT_SW_CHRG){
            TaskShowDateAndCharge();
        }else if(button_state == BUT_SET_TIME){
            TaskSetTime();
        }else if(button_state == BUT_SLEEP){
            //do nothig
        }
        
		PcIntInit();
    }
}

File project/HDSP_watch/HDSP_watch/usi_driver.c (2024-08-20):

/*
 * usi_driver.c
 *
 * Created: 01.08.2022 13:24:52
 *  Author: drspa
 */ 

#include "usi_driver.h"

// Port initialization
void PortInit(void)
{
    CLKPR = 0x80;
    CLKPR = 0x00;
    DDRB = 0x0F;
}

void PcIntInit(void)
{
    GIMSK |= (1 << PCIE);
    PCMSK |= (1 << PCINT4); // enable interrupt from pin PC4
    sei(); // enable all interrupts
}

void PcIntDeinit(void)
{
    GIMSK = 0x00;
    PCMSK = 0x00;
    cli(); // disables all interrupts
}

void PWMInit(void)
{
	TCCR1 |= (1<<CS12)|(1<<CS11)|(1<<CS10); // clk_t1/64
	TCCR0A |= (1<<WGM01);
	TCCR0B |= (1<<CS01); // clk_t0/8
	// clk_t1 = clk_t0 = 8 MHz	

	OCR0A = CNT_TOP;
	OCR0B = CNT_TOP/4;
}

void SPIInit(void)
{
	USICR = 0x00;
	USICR |= (1<<USIWM0);
	PORTB |= (1<<PB2)|(1<<PB3);
}

void SPISend(uint8_t byte)
{
	uint8_t i=0;
	USIDR = byte;
	while (i<7) {
		USICR |= (1<<USITC);
		USICR |= (1<<USICLK)|(1<<USITC);
		i++;
	}
}

void I2CInit(void)
{
	USICR = 0x00;
	PORTB &= ~(1<<PB3);
	USICR |= (1<<USIWM1);
	USIDR = 0x80;
	PORTB |= (1<<PB0)|(1<<PB2);
	USISR |= (1<<USISIF);
}

void I2CStart(void)
{
	TCNT0 = CNT_TOP-1;
	USIDR = 0x80;
	USICR |= (1<<USICS0);
	_delay_us(10);
	USISR |= (1<<USISIF);
	USICR |= (1<<USITC);
	_delay_us(3);
}

void I2CRepStart(void)
{
	TCNT0 = 0x00;
	USIDR = 0x80;
	_delay_us(3);
	USICR |= 0x01;
	_delay_us(5);
	TCNT0 = CNT_TOP - 1;
	_delay_us(6);
	USISR |= (1<<USISIF);
	USICR |= 0x01;
	_delay_us(3);
}

void I2CStop(void)
{
	USICR |= 0x01;
	_delay_us(5);
	USICR &= ~(1<<USICS0);
	USIDR = 0x80;
	USISR |= (1<<USIPF);
	_delay_us(5);
}

void I2CSendByte(uint8_t byte)
{
	USISR = 0x00;
	TCNT0 = 0x00;
	USIDR = byte;
	
	while((USISR & 0x09) != 0x09) {

		if((TIFR & (1 << OCF0B)) == (1 << OCF0B)){
			USICR |= (1 << USITC);
			_delay_us(CNT_TOP/2);
			USICR |= (1 << USITC);
			TIFR |= (1 << OCF0B);
		}
		
		if((USISR & 0x08) == 0x08){
			DDRB &= ~(1 << PB0);
			PORTB &= ~(1 << PB0);
		}
	}
	DDRB |= (1 << PB0);
	PORTB |= (1 << PB0);
	USIDR = 0x00;
}

uint8_t I2CReadByte(uint8_t ack)
{
	uint8_t byte=0, lock=0;
	USISR = 0x00;
	TCNT0 = 0x00;
	
	DDRB &= ~(1 << PB0);
	PORTB &= ~(1 << PB0);
	
	while((USISR & 0x09) != 0x09) {

		if((TIFR & (1 << OCF0B)) == (1 << OCF0B)){
			USICR |= (1 << USITC);
			_delay_us(CNT_TOP/2+10);
			USICR |= (1 << USITC);
			TIFR |= (1 << OCF0B);
		}
		
		if((USISR & 0x08) == 0x08 && !lock){
			byte = USIDR;
			lock=1;
			
			DDRB |= (1 << PB0);
			if(!ack) PORTB &= ~(1 << PB0);
			else USIDR |= 0x80, PORTB |= (1 << PB0);
		}
	}
	
	if(ack) USISR |= (1<<USISIF);
	PORTB |= (1 << PB0);
	USIDR = 0x00;

	return byte;
}

// this interrupt makes MCU leave sleep mode
ISR(PCINT0_vect)
{
    GIMSK = 0x00;
    PCMSK = 0x00;
}

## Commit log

2023-03-26 PCB files and source code were added
    [Control_Supply_PCB.GBL, Control_Supply_PCB.GBO, Control_Supply_PCB.GBP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]
2023-03-26 extra directories were deleted
    [Control_Supply_PCB.GBL, Control_Supply_PCB.GBO, Control_Supply_PCB.GBP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]
2024-08-20 code is refactored: added separate tasks for showing time, date and settings
    [Control_Supply_PCB.PcbDoc, HDSP_watch.PrjPcb, Watch_PCB.PcbDoc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]
